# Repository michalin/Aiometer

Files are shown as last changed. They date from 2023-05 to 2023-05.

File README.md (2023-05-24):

# All-In-One Meter
## What It Is
A device that can be (almost) everything. Clock, calendar, stock ticker or weather station. The data is retrieved public REST APIs over the Internet and displayed on VFD tubes. REST stands for REpresentational State Transfer, API for Application Programming Interface. This refers to a programming interface that describes the communication between applications (e.g. apps or IoT devices) and web services in networks. You can find a good choice of public REST APIs here: https://github.com/public-apis/public-apis   
An ESP32 handles both the connection via REST APIs and the control of the VFD tubes. The APIs to be accessed are configured in a JSON file. This provides the greatest possible flexibility. The device is controlled by a rotary encoder. This allows to select a specific web service (or its REST API) as well as the individual data points returned by it.   
There are still large stocks of the soviet VFD tubes type IV-11, so they can be purchased cheaply via Ebay or online stores. Under the tubes are WS2812 compatible RGB LEDs, which provide a nice color accent.

## Configuration
The device's configuration can be modified by editing the 'data/settings.json' file, which allows customization of the following parameters:
- WLAN SSID and password
- Hostname for remote access
- NTP server address
- Time zone
- Date and time format using standard date and time format specifiers
- LED colors while connecting to WLAN or waiting for server response
- Array with API queries:
  - Alias: String displayed on the tubes when a query is selected
  - Refresh: Interval at which data is polled in seconds
  - URL: API URL
  - GET: Array with the values of interest
- Array with APIs of devices to control
  - Alias: String displayed on the tubes when a query is selected
  - URL: URL of device to control
  - Value: Value to send to the device after it has been selected
  - Step, Min, Max: How the value changes, when the encoder is turned

The settings.json file can be easily uploaded to the SPIFFs filesystem of the ESP32 using the provided batch file "spiffs.bat".

## Usage
### Query APIs
To select a query, press and hold the rotary encoder while turning it until the desired query's alias appears, then release it. Rotate the rotary encoder to choose a data item returned by the query.
### Control APIs
To modify the LED color or brightness, or control an IoT device, quickly press the rotary encoder twice within one second. Press and hold the encoder while turning it until the alias of the desired device to control is displayed on the tubes, then release it. Rotating the encoder sends the value to the device.

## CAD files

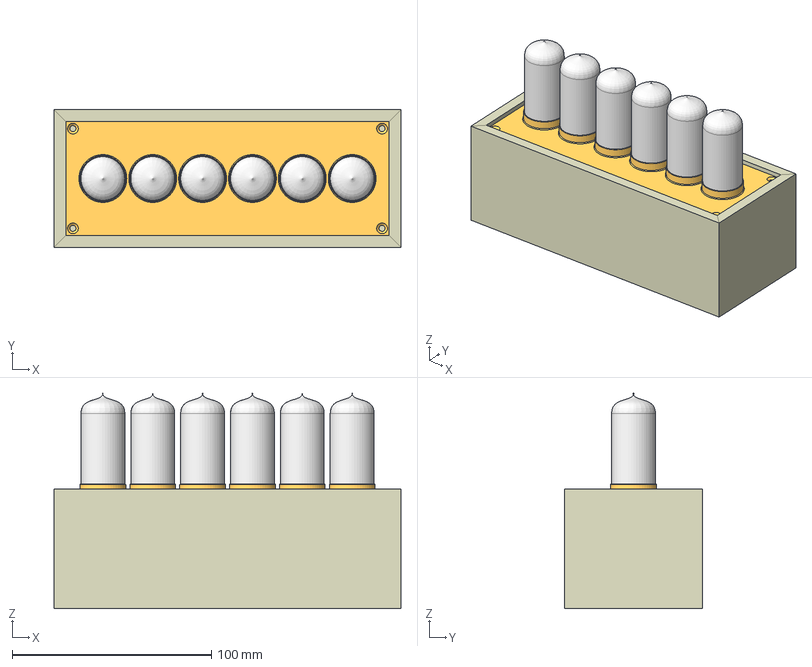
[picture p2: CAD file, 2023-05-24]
freecad/aiometer.FCStd
174.0 x 69.0 x 108.0 mm
Top_sheet
VFDtube x 6

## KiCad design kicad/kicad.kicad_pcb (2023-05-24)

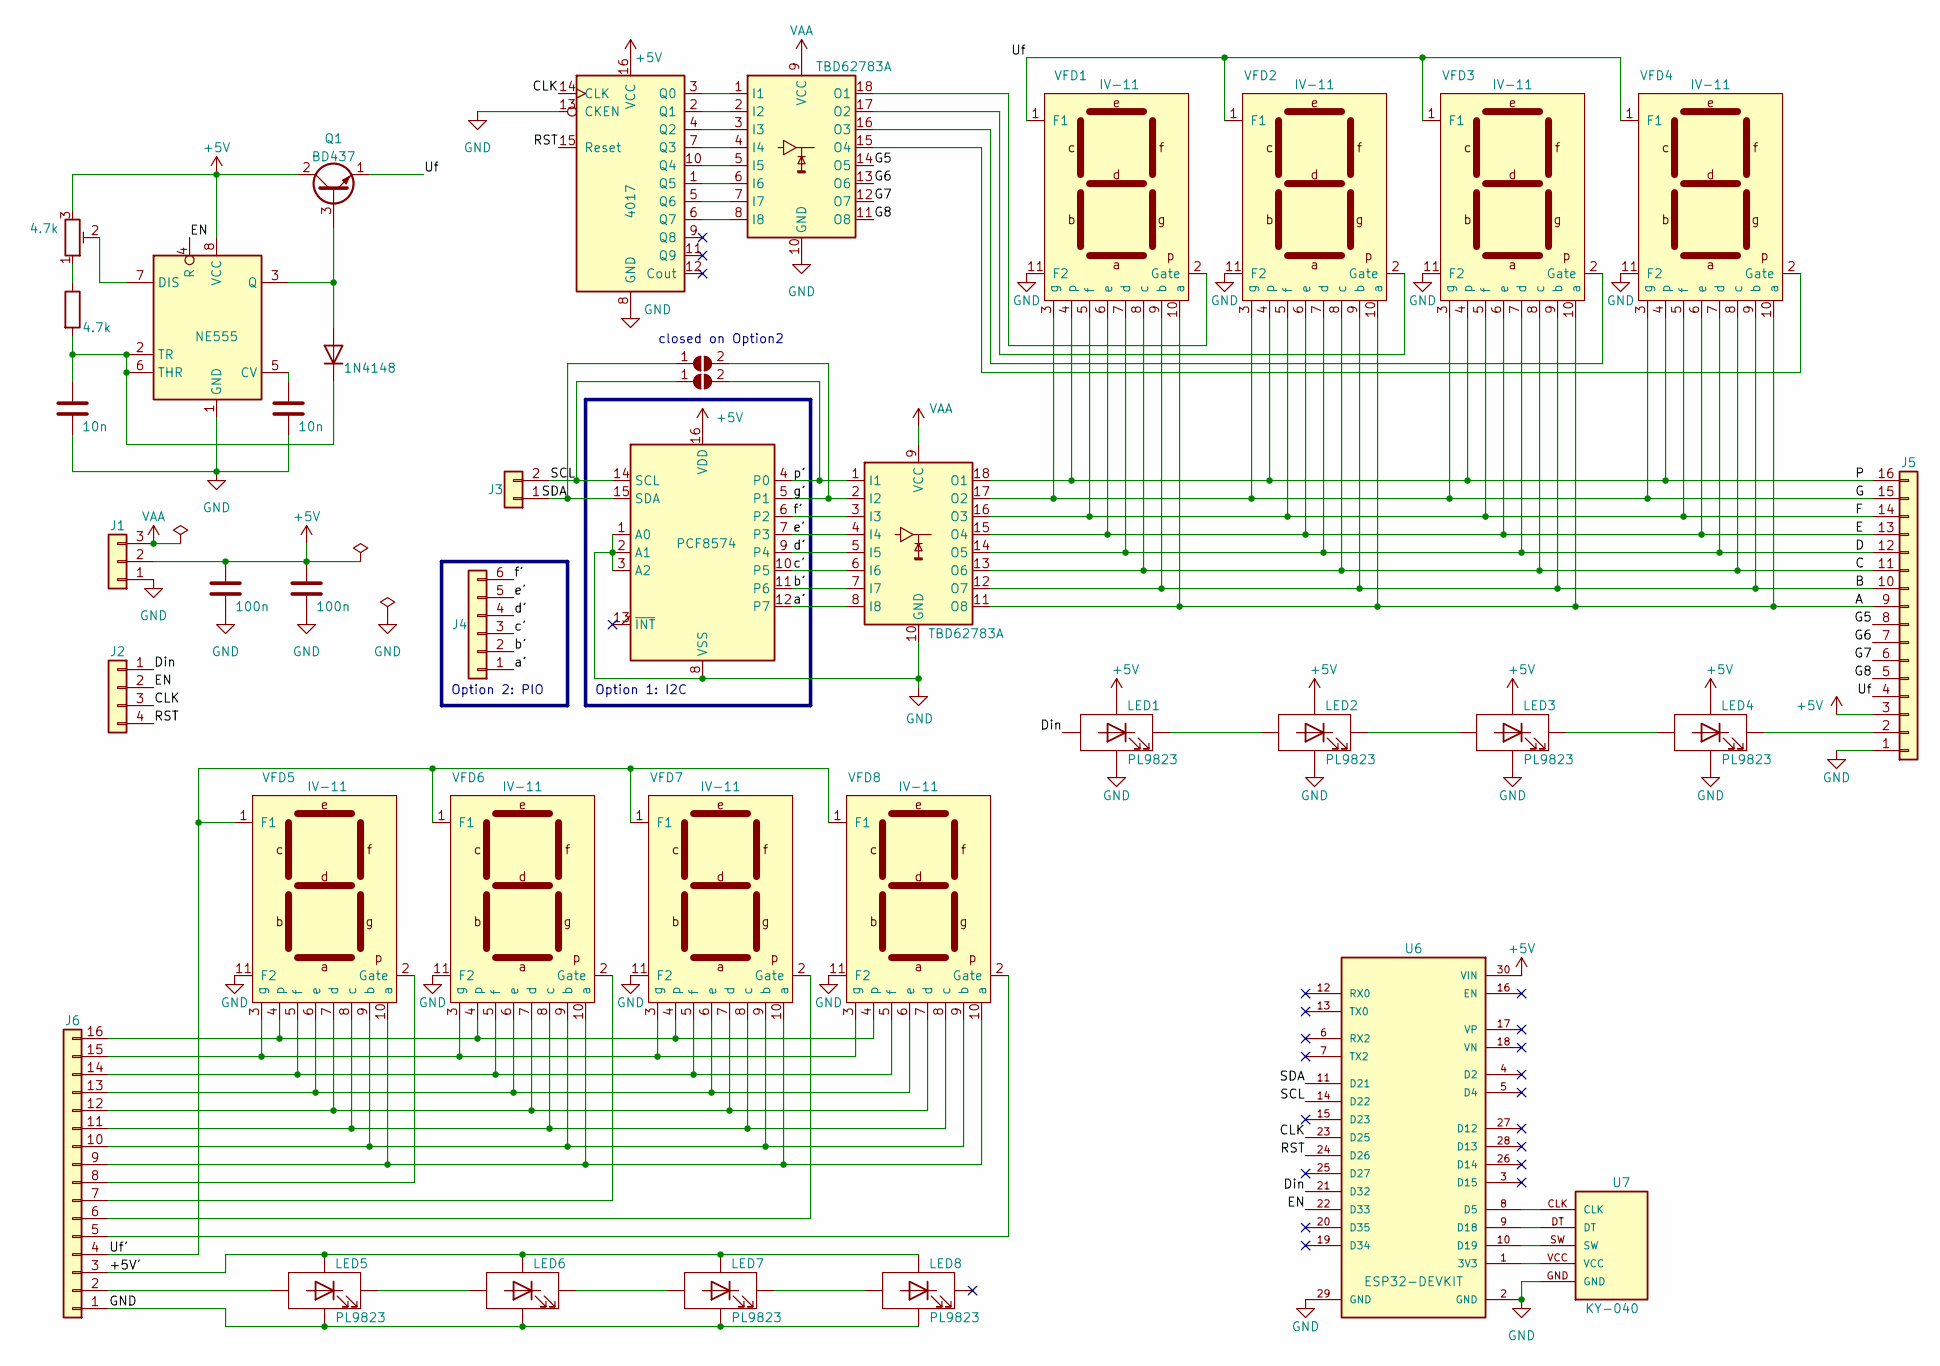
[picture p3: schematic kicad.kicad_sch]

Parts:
C1, C2: 10n; C_Disc_D3.4mm_W2.1mm_P2.50mm
C3, C4: 100n; C_Disc_D5.0mm_W2.5mm_P2.50mm
D1: 1N4148; D_DO-35_SOD27_P7.62mm_Horizontal
J1: Conn_01x03; Molex_KK-254_AE-6410-03A_1x03_P2.54mm_Vertical
J2: Conn_01x04; Molex_KK-254_AE-6410-04A_1x04_P2.54mm_Vertical
J3: Conn_01x02; conn_I2C
J4: Conn_01x06; conn_option2_PIO
J5, J6: Conn_01x16; conn_extender
JP1, JP2: SolderJumper_2_Open; SolderJumper-2_P1.3mm_Open_RoundedPad1.0x1.5mm
LED1, LED2, LED3, LED4, LED5, LED7, LED8: PL9823; LED_PL9823-F5
LED6: LED-PL9823; LED_PL9823-F5
Q1: BD437; TO-126-3
R1: 4.7k; R_Axial_DIN0207_L6.3mm_D2.5mm_P7.62mm_Horizontal
RV1: 4.7k; Potentiometer_Piher_PT-10-V10_Vertical
U1: NE555; DIP-8_W7.62mm_Socket
U2: 4017; DIP-16_W7.62mm_Socket
U3, U5: TBD62783A; DIP-18_W7.62mm_Socket
U4: PCF8574; DIP-16_W7.62mm_Socket
U6: ESP32-DEVKIT; MODULE_ESP32_DEVKIT_V1; PARTREV N/A
U7: KY-040; KY-040-PORT
VFD1, VFD2, VFD3, VFD4, VFD5, VFD6, VFD7, VFD8: IV-11; VFD-IV11

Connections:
+5V: C3.1, C4.1, J1.2, J5.3, LED1.3 (VDD), LED2.3 (VDD), LED3.3 (VDD), LED4.3 (VDD), Q1.2 (C), RV1.3, U1.8 (VCC), U2.16 (VCC), U4.16 (VDD), U6.30 (VIN)
/+5V': J6.3, LED5.3 (VDD), LED6.3 (VDD), LED7.3 (VDD), LED8.3 (VDD)
/A: J5.9, U5.11 (O8), VFD1.10 (a), VFD2.10 (a), VFD3.10 (a), VFD4.10 (a)
/B: J5.10, U5.12 (O7), VFD1.9 (b), VFD2.9 (b), VFD3.9 (b), VFD4.9 (b)
/C: J5.11, U5.13 (O6), VFD1.8 (c), VFD2.8 (c), VFD3.8 (c), VFD4.8 (c)
/CLK: J2.3, U2.14 (CLK), U6.23 (D25)
/D: J5.12, U5.14 (O5), VFD1.7 (d), VFD2.7 (d), VFD3.7 (d), VFD4.7 (d)
/Din: J2.1, LED1.4 (Din), U6.21 (D32)
/E: J5.13, U5.15 (O4), VFD1.6 (e), VFD2.6 (e), VFD3.6 (e), VFD4.6 (e)
/EN: J2.2, U1.4 (R), U6.22 (D33)
/F: J5.14, U5.16 (O3), VFD1.5 (f), VFD2.5 (f), VFD3.5 (f), VFD4.5 (f)
/G: J5.15, U5.17 (O2), VFD1.3 (g), VFD2.3 (g), VFD3.3 (g), VFD4.3 (g)
/G5: J5.8, U3.14 (O5)
/G6: J5.7, U3.13 (O6)
/G7: J5.6, U3.12 (O7)
/G8: J5.5, U3.11 (O8)
/P: J5.16, U5.18 (O1), VFD1.4 (p), VFD2.4 (p), VFD3.4 (p), VFD4.4 (p)
/RST: J2.4, U2.15 (Reset), U6.24 (D26)
/SCL: J3.2, JP2.1 (A), U4.14 (SCL), U6.14 (D22)
/Uf: J5.4, Q1.1 (E), VFD1.1 (F1), VFD2.1 (F1), VFD3.1 (F1), VFD4.1 (F1)
/Uf': J6.4, VFD5.1 (F1), VFD6.1 (F1), VFD7.1 (F1), VFD8.1 (F1)
/a': J4.1, U4.12 (P7), U5.8 (I8)
/b': J4.2, U4.11 (P6), U5.7 (I7)
/c': J4.3, U4.10 (P5), U5.6 (I6)
/d': J4.4, U4.9 (P4), U5.5 (I5)
/e': J4.5, U4.7 (P3), U5.4 (I4)
/f': J4.6, U4.6 (P2), U5.3 (I3)
/g': JP1.2 (B), U4.5 (P1), U5.2 (I2)
/p': JP2.2 (B), U4.4 (P0), U5.1 (I1)
GND: C1.2, C2.2, C3.2, C4.2, J1.1, J5.1, J6.1, LED1.2 (GND), LED2.2 (GND), LED3.2 (GND), LED4.2 (GND), LED5.2 (GND), LED6.2 (GND), LED7.2 (GND), LED8.2 (GND), U1.1 (GND), U2.8 (GND), U2.13 (CKEN), U3.10 (GND), U4.1 (A0), U4.2 (A1), U4.3 (A2), U4.8 (VSS), U5.10 (GND), U6.2 (GND), U6.29 (GND), U7.GND, VFD1.11 (F2), VFD2.11 (F2), VFD3.11 (F2), VFD4.11 (F2), VFD5.11 (F2), VFD6.11 (F2), VFD7.11 (F2), VFD8.11 (F2)
unnamed: D1.2 (A), Q1.3 (B), U1.3 (Q)
unnamed: C2.1, D1.1 (K), R1.2, U1.2 (TR), U1.6 (THR)
unnamed: J3.1, JP1.1 (A), U4.15 (SDA), U6.11 (D21)
unnamed: J5.2, LED4.1 (Dout)
unnamed: J6.2, LED5.4 (Din)
unnamed: J6.5, VFD8.2 (Gate)
unnamed: J6.6, VFD7.2 (Gate)
unnamed: J6.7, VFD6.2 (Gate)
unnamed: J6.8, VFD5.2 (Gate)
unnamed: J6.9, VFD5.10 (a), VFD6.10 (a), VFD7.10 (a), VFD8.10 (a)
unnamed: J6.10, VFD5.9 (b), VFD6.9 (b), VFD7.9 (b), VFD8.9 (b)
unnamed: J6.11, VFD5.8 (c), VFD6.8 (c), VFD7.8 (c), VFD8.8 (c)
unnamed: J6.12, VFD5.7 (d), VFD6.7 (d), VFD7.7 (d), VFD8.7 (d)
unnamed: J6.13, VFD5.6 (e), VFD6.6 (e), VFD7.6 (e), VFD8.6 (e)
unnamed: J6.14, VFD5.5 (f), VFD6.5 (f), VFD7.5 (f), VFD8.5 (f)
unnamed: J6.15, VFD5.3 (g), VFD6.3 (g), VFD7.3 (g), VFD8.3 (g)
unnamed: J6.16, VFD5.4 (p), VFD6.4 (p), VFD7.4 (p), VFD8.4 (p)
unnamed: LED1.1 (Dout), LED2.4 (Din)
unnamed: LED2.1 (Dout), LED3.4 (Din)
unnamed: LED3.1 (Dout), LED4.4 (Din)
unnamed: LED5.1 (Dout), LED6.4 (Din)
unnamed: LED6.1 (Dout), LED7.4 (Din)
unnamed: LED7.1 (Dout), LED8.4 (Din)
unnamed: R1.1, RV1.1
unnamed: C1.1, U1.5 (CV)
unnamed: RV1.2, U1.7 (DIS)
unnamed: U2.3 (Q0), U3.1 (I1)
unnamed: U2.2 (Q1), U3.2 (I2)
unnamed: U2.4 (Q2), U3.3 (I3)
unnamed: U2.7 (Q3), U3.4 (I4)
unnamed: U2.10 (Q4), U3.5 (I5)
unnamed: U2.1 (Q5), U3.6 (I6)
unnamed: U2.5 (Q6), U3.7 (I7)
unnamed: U2.6 (Q7), U3.8 (I8)
unnamed: U3.18 (O1), VFD1.2 (Gate)
unnamed: U3.17 (O2), VFD2.2 (Gate)
unnamed: U3.16 (O3), VFD3.2 (Gate)
unnamed: U3.15 (O4), VFD4.2 (Gate)
unnamed: U6.1 (3V3), U7.VCC
unnamed: U6.8 (D5), U7.CLK
unnamed: U6.9 (D18), U7.DT
unnamed: U6.10 (D19), U7.SW
VAA: J1.3, U3.9 (VCC), U5.9 (VCC)

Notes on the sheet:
closed on Option2
Option 2: PIO
Option 1: I2C

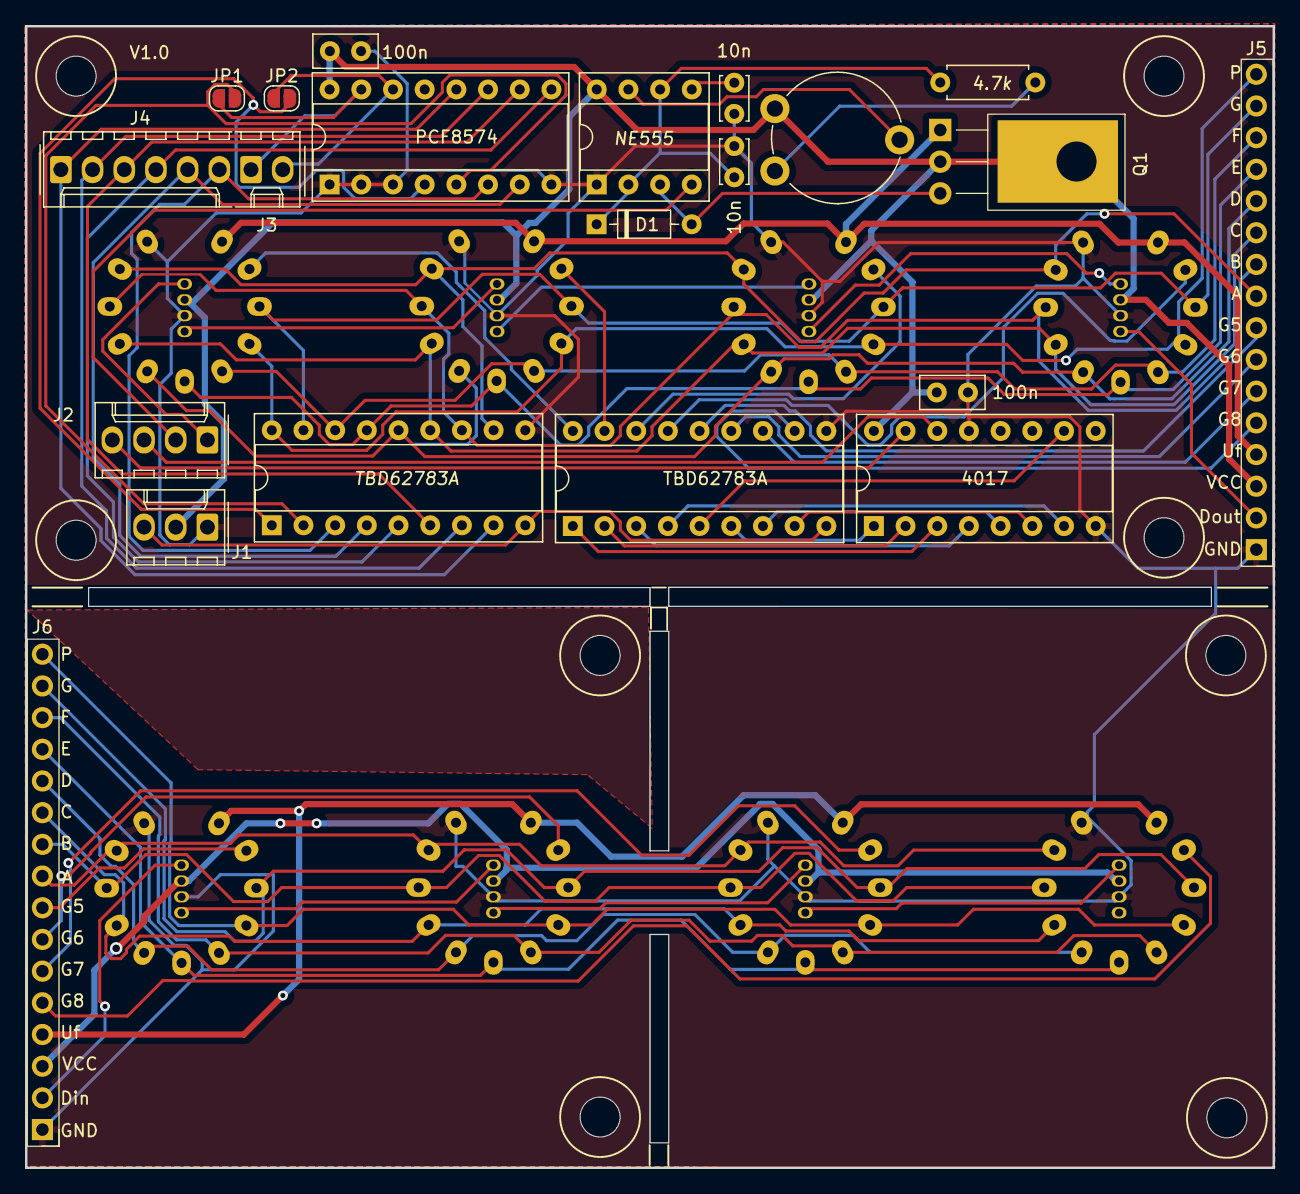
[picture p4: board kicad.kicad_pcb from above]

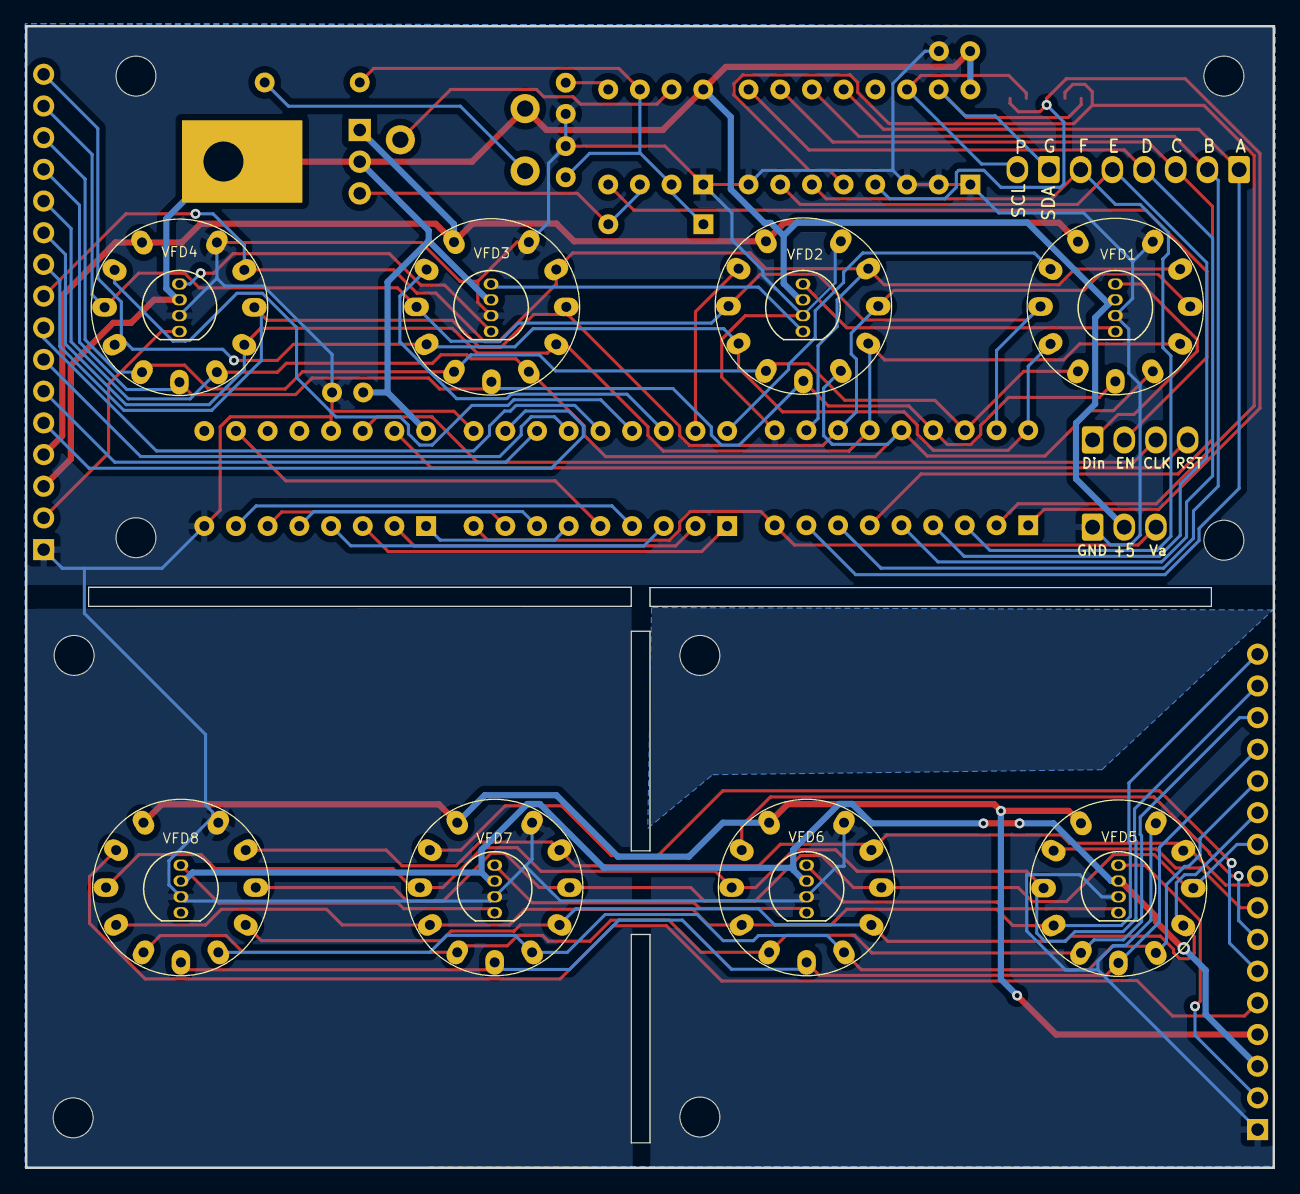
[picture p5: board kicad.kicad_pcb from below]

Board: 2 copper layers, 100.0 x 91.5 mm, 45 parts (16 on the bottom side), 69 nets.

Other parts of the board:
M1, M2, M3, M4, M6, M7, M9, M10: MountingHole_3.2mm_M3

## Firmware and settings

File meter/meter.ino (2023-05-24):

#ifdef USE_OTA
#include <AsyncElegantOTA.h>
#endif
#include <Arduino_ConnectionHandler.h>
#include <mdns.h>
#include <Adafruit_NeoPixel.h>
#include <EasyButton.h>
#include <string>
#include <ArduinoJson.h>
#include <WiFiClientSecure.h>
#include <HTTPClient.h>
#include <time.h>
#include <ESPAsyncWebServer.h>
#include <FS.h>
#include <SPIFFS.h>
#include "vfd.h"
// #include "errors.h"

#define ENC_CLK 5
#define ENC_DT 18
#define ENC_SW 19
#define LED_PIN 32
#define EN_PIN 33
#define CLOCK_TIMER_PERIOD 1000000
#define STATUS_IDLE 0
#define STATUS_IDLE_PENDING 0x10
#define STATUS_ON 1
#define STATUS_SET 2
#define SET_LED_HUE 0
#define SET_LED_VAL 1
#define MULTIPLEX_PRIORITY 6
#define HTTP_TIMEOUT 20000
#define CURRENT_QUERY current_selected - 1
#define set_ledcolor(color)     \
    neopixel.fill(color, 0, 0); \
    neopixel.show()
#define J_COLORHSV Adafruit_NeoPixel::ColorHSV(j_settings["settings"][SET_LED_HUE]["value"], 255, j_settings["settings"][SET_LED_VAL]["value"])
#define J_COLORRGB(key) Adafruit_NeoPixel::Color(j_settings[key][1], j_settings[key][0], j_settings[key][2])
#define J_SETTING j_settings["settings"][current_selected]
#define SETTINGS_FNAME "/settings.json"

#define DEBUG                      \
    #ifdef DEBUG Serial.printf(x); \
    #endif

File json_file; // settings.json
WiFiConnectionHandler wificonnection("","");
//WiFiClientSecure *httpsClient;// = new WiFiClientSecure;
//WiFiClient *httpClient;// = new WiFiClient;
DynamicJsonDocument j_settings(10000);
String server_response;
EasyButton knob_clk(ENC_CLK, 35, false);
EasyButton knob_dt(ENC_DT, 35, false);
EasyButton knob_sw(ENC_SW, 35, false);
int current_item, items_max_index;              // Changed when knob is turned
int current_selected = 1, selections_max_index; // Changed when knob is turned while being pressed
int saved_selected = current_selected;          // Used to remember last selection before idle
int saved_item;
Adafruit_NeoPixel neopixel(8, LED_PIN);
AsyncWebServer server(80);
esp_timer_handle_t clock_timer_handle;
uint8_t status = STATUS_ON;
void clock_callback(void *);

void getCurrentItem(int query, int item)
{
    // Serial.printf("-->getCurrentItem(%d, %d)\n",query,item);
    if(server_response == "")
        return;
    JsonObject jitem = j_settings["queries"][query]["get"][item].as<JsonObject>();
    DynamicJsonDocument jresponse(ESP.getMaxAllocHeap());
    deserializeJson(jresponse, server_response);
    selections_max_index = j_settings["queries"].size();
    JsonVariant jresp = jresponse;
    while (jitem.nesting() >= 1)
    {
        for (JsonPair p : jitem)
        {
            const char *key = p.key().c_str();
            JsonVariant val = p.value();
            jitem = jitem[key];
            // Serial.printf("Pair: {\"%s\":\"%s\"}\n", p.key().c_str(), p.value().as<String>().c_str());
            // Serial.printf("Nesting: %d, key: %s\n",jresp.nesting(),key);
            if (jresp.nesting() == 1)
            {
                char buf[128];
                const char *fmt = p.value();
                sprintf(buf, fmt, jresp[key].as<String>().c_str());
                vfd_set(buf);
            }

            if (jresp.is<JsonObject>())
            {
                // Serial.printf("Object: %s\n", jresp.as<String>().c_str());
                jresp = jresp[key];
            }
            else if (jresp.is<JsonArray>())
            {
                // Serial.printf("Array: %s\n", jresp.as<String>().c_str());
                jresp = jresp[atoi(key)];
            }
            else
                Serial.printf("Error: %s\n", jresp.as<String>().c_str());

            if (jresponse.overflowed())
                Serial.println("JSON document OVERFLOW");
        }
    }
}

HTTPClient https; 
WiFiClient *wifiClient = new WiFiClient();
WiFiClient *wifiClientSecure = new WiFiClientSecure();
int get_request(String url)
{
    //Serial.printf("-->get_request(%s)\n", url.c_str());
    server_response = "";
    int httpCode;
    https.setTimeout(HTTP_TIMEOUT);
    if (url.indexOf("localhost") < 0)
    {
        set_ledcolor(J_COLORRGB("ledcolor_wait")); // Do not change led color when working as clock
    }
    String data = J_SETTING["value"].as<String>();
    if (data)
    {
        const char *url_c = url.c_str();
        char buf[100];
        sprintf(buf, url_c, data.c_str());
        url = buf;
    }
    url.replace(" ", "%20");
    // Serial.println("accessing url: " + url);*/
    if (url.startsWith("http://") ? https.begin(*wifiClient, url) : https.begin(url))
    {
        vTaskPrioritySet(xTaskGetHandle("multiplex"), 10);
        httpCode = https.GET();
        vTaskPrioritySet(xTaskGetHandle("multiplex"), MULTIPLEX_PRIORITY);
        //Serial.printf("HTTP code: %d\n", httpCode);
        if (httpCode == HTTP_CODE_OK || httpCode == HTTP_CODE_MOVED_PERMANENTLY)
        {
            set_ledcolor(J_COLORHSV);
            server_response = https.getString();
            // Serial.println("Server response: " + server_response);
        }
        else
        {
            Serial.printf("[HTTPS] GET... failed, error: %s\n", https.errorToString(httpCode).c_str());
            set_ledcolor(J_COLORRGB("ledcolor_error"));
            vfd_set("http err" + String(httpCode));
        }
        https.end();
    } else
        Serial.println("request failed");

    //Serial.println("get_request()-->");
    return httpCode;
}
/*
    - sel_main has changed: Dislplay alias of selection
    - sel_item changed: Display item
*/
void on_selected(int sel_main, int sel_item)
{
    // Serial.printf("-->on_selected(%d, %d)\n", sel_main, sel_item);
    if (sel_main != current_selected)
    {
        esp_timer_stop(clock_timer_handle);
        if (sel_main == 0)
        {
            vfd_set("0ff");
            status = STATUS_IDLE_PENDING;
            // return;
        }
        else
        {
            // Serial.println(j_settings["queries"][sel_main - 1]["alias"].as<String>());
            vfd_set(j_settings["queries"][sel_main - 1]["alias"].as<String>());
            status = STATUS_ON;
        }
        current_selected = sel_main;
    }
    if (sel_item != current_item) // Item selected
    {
        getCurrentItem(CURRENT_QUERY, sel_item);
        current_item = sel_item;
    }
    items_max_index = j_settings["queries"][sel_main - 1]["get"].size() - 1;
}

void on_setting(int sel_main, bool direction)
{
    // Serial.printf("-->on_setting(%d, %d)\n", sel_main, direction);
    if (sel_main != current_selected)
    {
        current_selected = sel_main;
        vfd_set(J_SETTING["alias"].as<String>());
        return;
    }
    int value = (int)J_SETTING["value"];
    value += (2 * direction - 1) * (int)J_SETTING["step"];
    value = value > (int)J_SETTING["max"] ? (int)J_SETTING["min"] : value;
    value = value < (int)J_SETTING["min"] ? (int)J_SETTING["max"] : value;
    J_SETTING["value"] = value;
    get_request(J_SETTING["url"].as<String>());
    //clock_callback(NULL);
    vfd_set(String(value));
}

/*Functions for knob user interface*/
void on_knob_released()
{
    // Serial.printf("-->on_knob_released()\n");
    switch (status)
    {
    case STATUS_IDLE_PENDING: // Go to sleep
        status = STATUS_IDLE;
        saved_item = current_item;
        digitalWrite(EN_PIN, LOW);
        set_ledcolor(Adafruit_NeoPixel::Color(0, 0, 0));
        break;
    case STATUS_IDLE: // Wake up
        status = STATUS_ON;
        current_selected = saved_selected;
        current_item = saved_item;
        clock_callback(NULL);
        selections_max_index = j_settings["queries"].size();
        esp_timer_start_periodic(clock_timer_handle, CLOCK_TIMER_PERIOD * (int)j_settings["queries"][CURRENT_QUERY]["refresh"]);
        digitalWrite(EN_PIN, HIGH);
        set_ledcolor(J_COLORHSV);
        // Serial.printf("Idle->On: Current: %d, saved: %d\n", current_item, saved_item);
        break;
    case STATUS_ON: // Selected query has changed
        saved_selected = current_selected;
        current_item = 0;
        clock_callback(NULL);
        esp_timer_start_periodic(clock_timer_handle, CLOCK_TIMER_PERIOD * (int)j_settings["queries"][CURRENT_QUERY]["refresh"]);
        // Serial.printf("On: Current: %d, saved: %d\n", current_item, saved_item);
    }
}

/* Knob turned: Set item, Knob pressed while turned: Set query*/
void on_knob_turned()
{
    // Serial.printf("-->on_knob_turned()\n");
    if (status == STATUS_IDLE)
        return;

    int sel_main = current_selected;
    int sel_item = current_item;
    if (knob_sw.isPressed()) // Pressed: select query or setting
    {
        if (knob_dt.isPressed()) // Turn right
            sel_main < selections_max_index ? sel_main++ : sel_main = 0;
        else
            sel_main > 0 ? sel_main-- : sel_main = selections_max_index;
    }
    else
    {
        if (knob_dt.isPressed()) // Turn right
            sel_item < items_max_index ? sel_item++ : sel_item = 0;
        else
            sel_item > 0 ? sel_item-- : sel_item = items_max_index;
    }
    if (status == STATUS_SET)
        on_setting(sel_main, knob_dt.isPressed());
    else
        on_selected(sel_main, sel_item);
}

/*Pressing the knob twice whithin 1s switches to settings mode and back*/
void on_knob_dblclick()
{
    // Serial.printf("-->on_knob_dblclick()\n");
    if (status == STATUS_SET)
    {
        status = STATUS_ON;
        current_item = saved_item;
        current_selected = saved_selected;

        clock_callback(NULL);
        esp_timer_start_periodic(clock_timer_handle, CLOCK_TIMER_PERIOD * (int)j_settings["queries"][CURRENT_QUERY]["refresh"]);
        selections_max_index = j_settings["queries"].size();
        json_file = SPIFFS.open(SETTINGS_FNAME, FILE_WRITE);
        serializeJsonPretty(j_settings, json_file);
        json_file.close();
        return;
    }
    esp_timer_stop(clock_timer_handle);
    saved_item = current_item;
    current_item = 0;
    current_selected = 0;
    selections_max_index = j_settings["settings"].size() - 1;
    status = STATUS_SET;
    vfd_set("ctrl");
}

/*  Called by RTOS. Reloads data at the interval specified in "refresh"*/
void clock_callback(void *arg)
{
    // Serial.println(j_settings["setttings"][CURRENT_QUERY]["url"].as<String>());
    int code = get_request(j_settings["queries"][CURRENT_QUERY]["url"].as<String>());
    if(!(code == HTTP_CODE_OK || code == HTTP_CODE_MOVED_PERMANENTLY)) //Workaround. This sometimes happens without reason.
    {
        vfd_set("wait");
        get_request(j_settings["queries"][CURRENT_QUERY]["url"].as<String>()); //Retry
    }
    getCurrentItem(CURRENT_QUERY, current_item);
}

/* responds to http access to localhost and returns current date and time
also used for configuration */
void on_http_local(AsyncWebServerRequest *request)
{
    //Serial.printf("-->on_http_local(%s):\n", request->url().c_str());
    if (request->url().equals("/time"))
    {
        struct tm timeinfo;
        if (!getLocalTime(&timeinfo))
        {
            Serial.println("Failed to obtain time");
            return;
        }
        const char *json = "{\"time\":\"%s\",\"date\":\"%s\"}";
        char time[12];
        strftime(time, 12, j_settings["timeformat"], &timeinfo);
        char date[12];
        strftime(date, 12, j_settings["dateformat"], &timeinfo);
        char buf[64];
        sprintf(buf, json, time, date);
        request->send(200, "text/plain", buf);
        return;
    }
    if (request->url().equals("/led"))
    {
        String argname = request->argName(0);
        int index;
        if (argname.equals("hue"))
            index = SET_LED_HUE;
        else if (argname.equals("value"))
            index = SET_LED_VAL;
        else
        {
            request->send(200, "text/plain", "unknown argument: " + argname);
            return;
        }
        j_settings["settings"][index]["value"] = (long)request->arg(argname).toInt();
        set_ledcolor(J_COLORHSV);
        request->send(200, "text/plain", argname + "=" + (j_settings["settings"][index]["value"].as<String>()));
        return;
    }
    if (request->url().equals("/tubes"))
    {
        request->send(200, "text/plain", "success");
    }
    request->send(200, "text/plain", "unknown");
}

void on_http_remote(AsyncWebServerRequest *request)
{
    int turn_direction = request->arg("dir").toInt();
    int pressed = request->arg("pressed").equals("true");
    // Serial.printf("-->on_http_remote(direction:%d, pressed: %d)\n", turn_direction, pressed);
    int sel_main = current_selected;
    int sel_item = current_item;
    if (pressed)
    {
        sel_main += turn_direction;
        if (sel_main > selections_max_index)
            sel_main = 0;
        if (sel_main < 0)
            sel_main = selections_max_index;
    }
    else
    {
        sel_item += turn_direction;
        if (sel_item > items_max_index)
            sel_item = 0;
        if (sel_item < 0)
            sel_item = items_max_index;
        if (turn_direction == 0)
        {
            sel_item = 0;
            on_knob_released();
        }
    }
    on_selected(sel_main, sel_item);

    DynamicJsonDocument jdoc(1024);
    jdoc["direction"] = turn_direction;
    jdoc["pressed"] = pressed;
    jdoc["vfd"] = "vfd";
    jdoc["refresh"] = j_settings["queries"][CURRENT_QUERY]["refresh"];
    request->send(200, "text/html", jdoc.as<String>());
    // Serial.printf("on_http_remote()-->\n");
}

void on_wlan_disconnected()
{
    Serial.println("-->on_wlan_disconnected()");
    set_ledcolor(J_COLORRGB("ledcolor_error"));
    vfd_set("wlan err 2");
}
void on_wlan_error()
{
    Serial.println("-->on_wlan_error()");
    set_ledcolor(J_COLORRGB("ledcolor_error"));
    vfd_set("wlan err 1");
}
void on_wlan_connected()
{
    // Serial.println("-->on_wlan_connected()");
    mdns_init();
    mdns_hostname_set(j_settings["hostname"]);
    DefaultHeaders::Instance().addHeader(F("Access-Control-Allow-Origin"), F("*")); //CORS magic
    // Local webserver for time and date
    server.on("/", HTTP_ANY, [](AsyncWebServerRequest *request) { // Content of settings.json
        File web = SPIFFS.open("/index.htm", FILE_READ);
        request->send(200, "text/html", web.readString());
        web.close();
    });
    server.on("/time", HTTP_GET, on_http_local);
    server.on("/led", HTTP_GET, on_http_local);
    server.on("/tubes", HTTP_GET, on_http_local);
    server.on("/remote", HTTP_GET, on_http_remote);
#ifdef USE_OTA
    AsyncElegantOTA.begin(&server);
#endif
    server.begin();
    clock_callback(NULL);

    configTime(3600 * (int)j_settings["gmtoffset_h"],
               3600 * (int)j_settings["daylightoffset_h"],
               j_settings["ntpserver"]);

    const esp_timer_create_args_t clock_timer_args = {
        .callback = &clock_callback};
    esp_timer_create(&clock_timer_args, &clock_timer_handle);
    esp_timer_start_periodic(clock_timer_handle, CLOCK_TIMER_PERIOD * (int)j_settings["queries"][CURRENT_QUERY]["refresh"]);
    set_ledcolor(J_COLORHSV);
}

void setup()
{
    Serial.begin(115200);
    neopixel.begin();
    set_ledcolor(Adafruit_NeoPixel::Color(0, 0, 0));

    // Init tubes
    vfd_init();
    vfd_set("Connecting to wlan");
    pinMode(EN_PIN, OUTPUT);
    digitalWrite(EN_PIN, HIGH);
    xTaskCreate( // Run tube multiplexing as own realtime task with high priority
        [](void *p)
        {
            while (1)
                vfd_multiplex();
        },
        "multiplex", /* Name of the task */
        10000,       /* Stack size in words */
        NULL,        /* Task input parameter */
        MULTIPLEX_PRIORITY,
        NULL); /* Task handle. */
               // 1);   /* Core */

    // Read settings
    if (!SPIFFS.begin())
    {
        Serial.println("SPIFFS Mount Failed");
        vfd_set("spiffs err");
        set_ledcolor(J_COLORRGB("ledcolor_error"));
        return;
    }
    Serial.println("SPIFFS mounted");
    json_file = SPIFFS.open(SETTINGS_FNAME, "r");
    if (!json_file.available())
    {
        set_ledcolor(J_COLORRGB("ledcolor_error"));
        vfd_set("json err 1");
        Serial.println("data/settings.json file not found. Upload to SPIFFS");
        return;
    }
    DeserializationError err = deserializeJson(j_settings, json_file);
    if (err)
    {
        Serial.print(F("settings.json deserialization error: "));
        Serial.println(err.c_str());
        set_ledcolor(J_COLORRGB("ledcolor_error"));
        vfd_set("json err 2");
        return;
    }
    json_file.close();
    neopixel.fill(J_COLORRGB("ledcolor_wait"));
    neopixel.show();
    items_max_index = j_settings["queries"][0]["get"].size() - 1;
    selections_max_index = j_settings["queries"].size(); // Including "off"
    wificonnection = WiFiConnectionHandler(j_settings["ssid"], j_settings["password"]);
    wificonnection.addCallback(NetworkConnectionEvent::DISCONNECTED, []()
                               { on_wlan_disconnected(); });
    wificonnection.addCallback(NetworkConnectionEvent::ERROR, []()
                               { on_wlan_error(); });
    wificonnection.addCallback(NetworkConnectionEvent::CONNECTED, []()
                               { on_wlan_connected(); });

    int cnt;
    // vfd_set("0123456789abcdefghijklmnopqrstuvwxyz");
    knob_clk.begin();
    knob_clk.onPressed(on_knob_turned);
    knob_sw.begin();
    knob_sw.onPressed(on_knob_released);
    knob_sw.onSequence(2, 1000, on_knob_dblclick);
}

NetworkConnectionState check;
void loop()
{
    static int t = millis();
    knob_clk.read();
    knob_dt.read();
    knob_sw.read();

    wificonnection.check();
}

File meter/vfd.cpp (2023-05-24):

/*This work is licensed under the Creative Commons Attribution-ShareAlike 4.0 International License.
To view a copy of this license, visit https://creativecommons.org/licenses/by-sa/4.0/deed.en
*/
#ifdef __AVR__
// #include <avr/power.h>
#include <avr/pgmspace.h>
#endif
#include <Wire.h>
#include "vfd.h"
#include <Adafruit_NeoPixel.h>
#include <string.h>

/*    _____
     |  e  |
    c|     |f
     |_____|
     |  d  |
    b|     |g
     |_____|.p
        a     */
#define NTUBES 6
#define SEG_A (1 << 7)
#define SEG_B (1 << 6)
#define SEG_C (1 << 5)
#define SEG_D (1 << 4)
#define SEG_E (1 << 3)
#define SEG_F (1 << 2)
#define SEG_G (1 << 1)
#define SEG_DP (1 << 0)

const uint8_t letters[] PROGMEM = {
    SEG_B + SEG_C + SEG_D + SEG_E + SEG_F + SEG_G, // A
    SEG_A + SEG_B + SEG_C + SEG_D + SEG_G,         // b
    SEG_A + SEG_B + SEG_C + SEG_E,                 // C
    SEG_A + SEG_B + SEG_D + SEG_G + SEG_F,         // d
    SEG_A + SEG_B + SEG_C + SEG_D + SEG_E,         // E
    SEG_B + SEG_C + SEG_D + SEG_E,                 // F
    SEG_A + SEG_B + SEG_C + SEG_E + SEG_G,         // G
    SEG_B + SEG_C + SEG_D + SEG_F + SEG_G,         // H
    SEG_G,                                         // I
    SEG_A + SEG_B + SEG_F + SEG_G,                 // J
    SEG_B + SEG_C + SEG_D,                         // K
    SEG_A + SEG_B + SEG_C,                         // L
    SEG_B + SEG_D + SEG_E + SEG_G,                 // M
    SEG_B + SEG_D + SEG_G,                         // N
    SEG_A + SEG_B + SEG_D + SEG_G,                 // O
    SEG_B + SEG_C + SEG_D + SEG_E + SEG_F,         // P
    SEG_C + SEG_D + SEG_E + SEG_F + SEG_G,         // Q
    SEG_B + SEG_D,                                 // R
    SEG_A + SEG_C + SEG_D + SEG_E + SEG_G,         // S
    SEG_A + SEG_B + SEG_C + SEG_D,                 // T
    SEG_A + SEG_B + SEG_C + SEG_F + SEG_G,         // U
    SEG_A + SEG_B + SEG_G,                         // V
    SEG_A + SEG_C + SEG_D + SEG_F,                 // W
    SEG_B + SEG_C + SEG_D + SEG_F + SEG_G,         // X
    SEG_A + SEG_C + SEG_D + SEG_F + SEG_G,         // Y
    SEG_A + SEG_B + SEG_D + SEG_E + SEG_F          // Z
};

const uint8_t numbers[] PROGMEM = {
    SEG_A + SEG_B + SEG_C + SEG_E + SEG_F + SEG_G,         // 0
    SEG_F + SEG_G,                                         // 1
    SEG_A + SEG_B + SEG_D + SEG_E + SEG_F,                 // 2
    SEG_A + SEG_D + SEG_E + SEG_F + SEG_G,                 // 3
    SEG_C + SEG_D + SEG_F + SEG_G,                         // 4
    SEG_A + SEG_C + SEG_D + SEG_E + SEG_G,                 // 5
    SEG_A + SEG_B + SEG_C + SEG_D + SEG_E + SEG_G,         // 6
    SEG_E + SEG_F + SEG_G,                                 // 7
    SEG_A + SEG_B + SEG_C + SEG_D + SEG_E + SEG_F + SEG_G, // 8
    SEG_A + SEG_C + SEG_D + SEG_E + SEG_F + SEG_G,         // 9
};

uint8_t i2caddr;
String vfdtxt; // Processed text to show on tubes
int txtlen;

void vfd_init(const uint8_t addr, const uint8_t rst_pin, const uint8_t clk_pin)
{
    Wire.begin();
    pinMode(rst_pin, OUTPUT);
    pinMode(clk_pin, OUTPUT);
    digitalWrite(RST, HIGH);
    digitalWrite(RST, LOW);
    i2caddr = addr;
}

int scroll_pos;
String ticker(String in, int tick_time)
{
    static uint32_t last_millis = millis();
    static uint32_t last_millis2 = millis();
    static String tick;
    bool run = false;

    if (millis() - last_millis2 > 2000) // Wait time over, start scrolling
    {
        run = true;
    }

    if (scroll_pos == 0) // New string, reset wait time
    {
        run = true;
        last_millis2 = millis();
    }

    if (millis() - last_millis > tick_time && run)
    {
        last_millis = millis();
        if (scroll_pos <= txtlen - NTUBES)
        {
            tick = "";
            int endpos = NTUBES;
            for (int i = scroll_pos; i < scroll_pos + endpos; i++)
            {
                in[i] == '.' ? endpos++ : endpos; // Copy one more
                tick += in[i];
            }
            scroll_pos++;
        }
        // Serial.println(tick + "--");
    }
    return tick;
}

uint8_t i = 0;
void vfd_multiplex()
{
    // Serial.println("-->vfd_multiplex()\n");
    static int last_millis = millis();
    if (millis() - last_millis < 1)
        return; // Execute at most every 2 milliseconds
    last_millis = millis();

    String vfdtext = vfdtxt;
    if (txtlen > NTUBES)
        vfdtext = ticker(vfdtxt, 300);

    Wire.beginTransmission(i2caddr);
    Wire.write(0); // Clear tubes
    Wire.endTransmission();
    if (vfdtext[++i] == 0) // End of string
    {
        digitalWrite(RST, HIGH);
        digitalWrite(RST, LOW);
        i = 0;
    }

    uint8_t c = vfdtext[i];
    if (c >= '0' && c <= '9')
        // c = numbers[c - '0'];
        c = pgm_read_byte_near(numbers + c - '0');
    else if (c >= 'a' && c <= 'z')
        // c = letters[c - 'a'];
        c = pgm_read_byte_near(letters + c - 'a');
    else
        switch (c)
        {
        case 32:
            c = 0;
            break;
        case '-':
            c = SEG_D;
            break;
        case '*': // Replacement for ° (Degree)
            c = SEG_C + SEG_D + SEG_E + SEG_F;
            break;
        default:
            c = 0;
        }

    if (vfdtext[i + 1] == '.') // also replacement for ':' and ','
    {
        c |= SEG_DP;
        i ? i += 1 : i;
    }
    if (i)
    {
        digitalWrite(CLK, HIGH);
        digitalWrite(CLK, LOW);
    }

    if (c)
    {
        Wire.beginTransmission(i2caddr);
        Wire.write(c);
        Wire.endTransmission();
    }
}

void vfd_set(String text)
{
    // Serial.printf("-->vfd_set(%s)\n", text.c_str());
    text.replace("°", "*");
    text.replace(":", ".");
    text.replace(",", ".");
    text.toLowerCase();
    txtlen = text.length();
    text.lastIndexOf(".") >= txtlen-NTUBES? txtlen-- : txtlen;
    //Serial.printf("text: %s, length: %d, index: %d\n", text.c_str(), txtlen, text.lastIndexOf("."));
    scroll_pos = 0;
    vfdtxt = text;
}
